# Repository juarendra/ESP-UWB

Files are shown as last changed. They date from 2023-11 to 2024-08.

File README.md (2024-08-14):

# ESP-UWB
This is PCB or Modul that combine ESP32 WROOM and DWM1004C in one Board, all pin are connected to header like ESP32 DEV KIT, and DWM1004C some pin are connected to SMD PAD on Bottom of PCB. You can find the gerber file, BOM LIST file and schematic file on this repository. 

## Table of Content

* [Product Specsification](#product-specsification)
* [Technical Spesification](#technical-spesification)
* [Priview Hardware](#priview-hardware)
* [Documentation](#documentation)
  * [Pinout Diagram](#pinout-diagram)
  * [Dimension](#dimension)
  * [BOM](#bom)
  * [Schematic](#schematic0)
  * [Example Program](#examples-program)
* [FAQ](#FAQ)

## Product Specsification
- esp32 wroom
- dwm1004c
- connected with serial uart between esp and dwm
- header i2c for oled display
- header pinout esp32
- pad smd dwm1004c
- modul charger tp4056
- switch on off

## Technical Spesification

| Features | Value |  
| --- | --- |
| Microcontroller | ESP32 |
| UWB Chip | DWM1004c |
| Dispaly | OLED 0.91 inch |
| USB To UART | FTDI 232XS |
| IC Charger | TP4056 |
| PSU | M3406 2.0V to 6.0V to 3.3V 800mA|

## Preview Hardware
<p align="center">
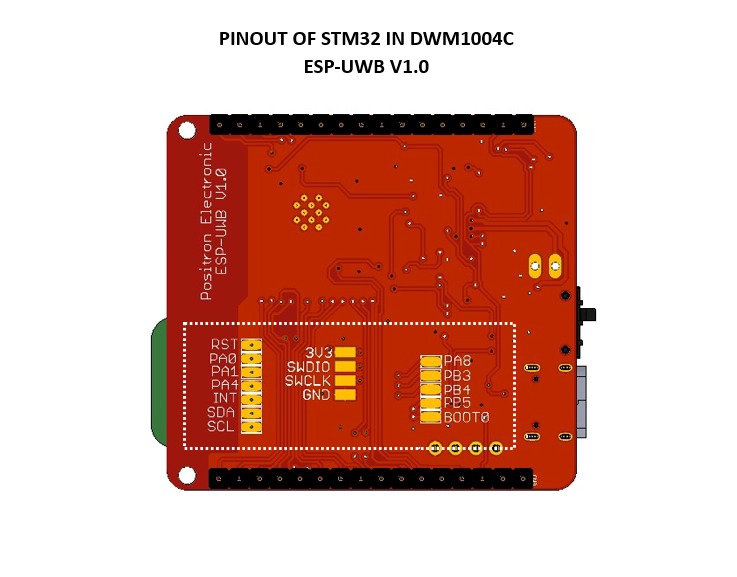
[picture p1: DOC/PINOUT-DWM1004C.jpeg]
  
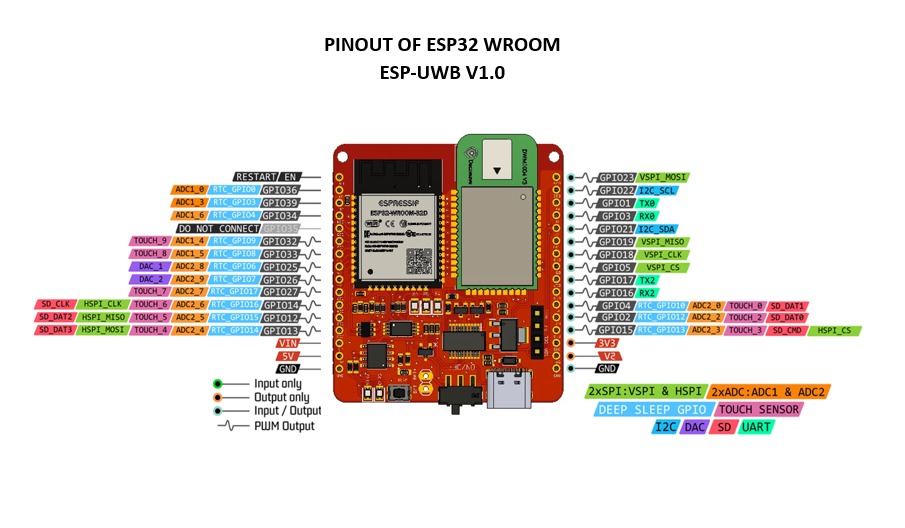
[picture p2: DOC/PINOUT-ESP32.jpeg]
  
</p>

## Documentation
### PINOUT
<p align="center">
  
</p>

### Dimension
- [Dimension](https://github.com/juarendra/ESP-UWB/blob/main/HARDWARE/dimension_esp-uwb.pdf)
### BOM
- [BOM](https://github.com/juarendra/ESP-UWB/blob/main/DOC/BOM_ESP-UWB.csv)
### Schematic
- Not Available
### Example Program
- [Example Program](https://github.com/juarendra/ESP-UWB/tree/main/FIRMWARE)

## Detail Connection ESP32 to DWM1004c
<p align="center">
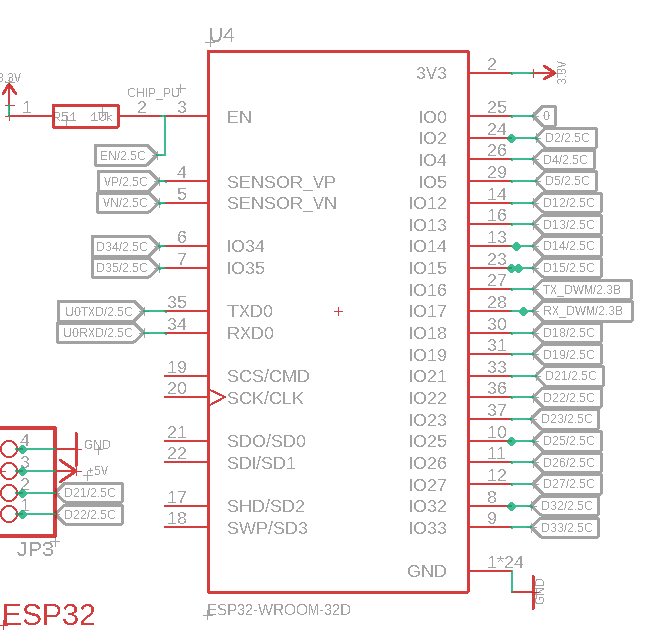
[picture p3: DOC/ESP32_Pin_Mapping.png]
  
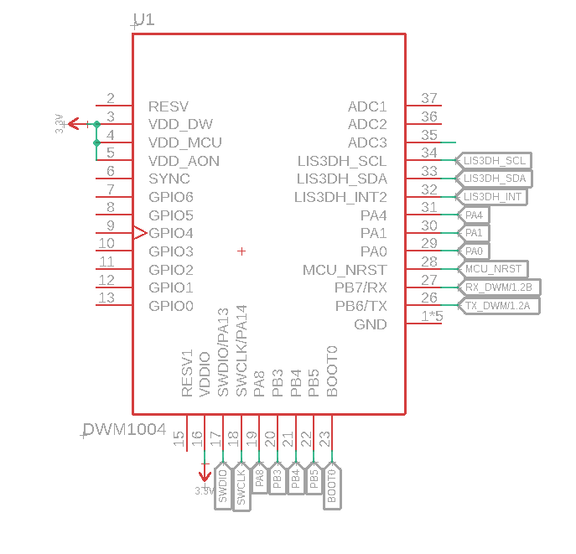
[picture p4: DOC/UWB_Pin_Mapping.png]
  
</p>
ESP32 and DWM1004c are connection with serial , you can see that ESP32 use pin IO16 and IO7 for serial and connected with DWM1004C with pin PB7 and PB6. Serial Connection is interface that STM32L have, and STM32 connected with DMW1000 with SPI. You must flash STM32 for reading data from DWM1000 and send it VIA Serial to ESP32.

You can flash STM32L using STlink and connected to SMD pad on Bottom of PCB

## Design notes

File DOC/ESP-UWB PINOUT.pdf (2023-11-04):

PINOUT OF STM32 IN DWM1004C ESP-UWB V1.0

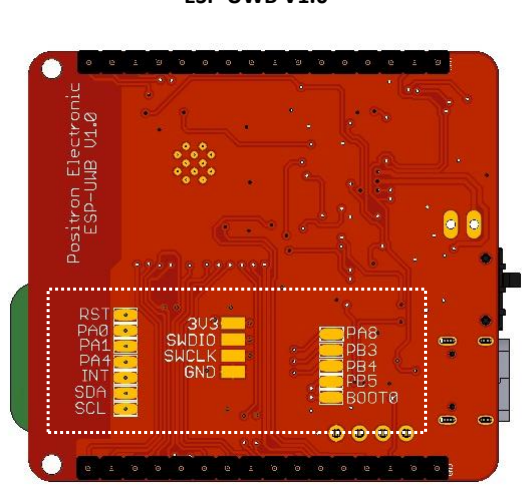
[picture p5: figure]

PINOUT OF ESP32 WROOM
ESP-UWB V1.0

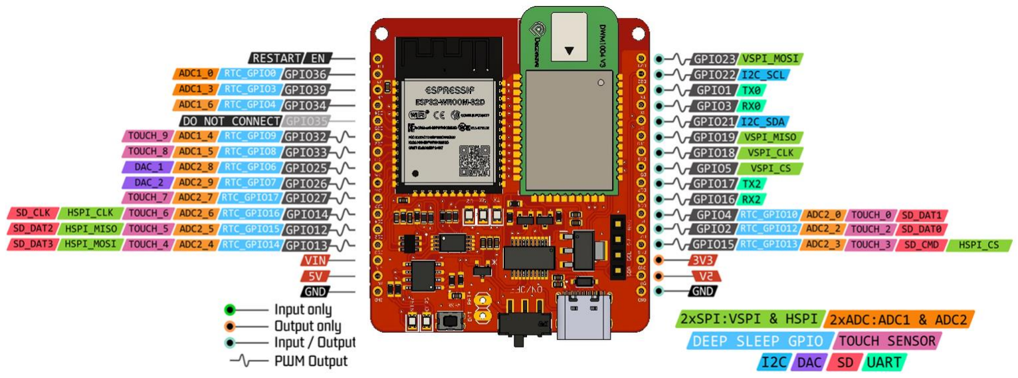
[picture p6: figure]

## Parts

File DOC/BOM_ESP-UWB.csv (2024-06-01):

Qty | Value | Device | Package | Parts | Description | AVAILABILITY | CHECK_PRICES | DESCRIPTION | DIGIKEY_PARTNUMBER | DIGIKEY_PRICE-STOCK | HEIGHT | LCSC_PART_NUMBER | LCSC_PRICE-STOCK | MANUFACTURER_NAME | MANUFACTURER_PART_NUMBER | MF | MOUSER_PART_NUMBER | MOUSER_PRICE-STOCK | MP | PACKAGE | POPULARITY | PRICE | PURCHASE-URL | SNAPEDA_LINK | VALUE
2 |  | HEADER-1X16_MIN | 1X16_ROUND_MIN | JP1, JP2 | PIN HEADER
1 |  | HEADER-1X4ROUND | 1X04_ROUND | JP3 | PIN HEADER
1 |  | PINHD-1X2 | 1X02 | BATT | PIN HEADER |  |  |  |  |  |  |  |  |  |  |  |  |  |  |  | 98
1 | 1.2k | ESR03EZPJ102 | RESC1608X55N | R8 | Thick Film Resistors - SMD 0603 1Kohm 5% Anti Surge AEC-Q200 |  |  | Thick Film Resistors - SMD 0603 1Kohm 5% Anti Surge AEC-Q200 | RHM1.0KDCT-ND | https://www.digikey.com/product-detail/en/rohm-semiconductor/ESR03EZPJ102/RHM1-0KDCT-ND/1762924 | 0.55mm |  |  | ROHM Semiconductor | ESR03EZPJ102 |  | 755-ESR03EZPJ102 | https://www.mouser.co.uk/ProductDetail/ROHM-Semiconductor/ESR03EZPJ102?qs=DyUWGjl%252BcVvjMuV%252BzioV7Q%3D%3D |  |  |  |  |  |  | 1k
1 | 100 | ESR03EZPJ102 | RESC1608X55N | R9 | Thick Film Resistors - SMD 0603 1Kohm 5% Anti Surge AEC-Q200 |  |  | Thick Film Resistors - SMD 0603 1Kohm 5% Anti Surge AEC-Q200 | RHM1.0KDCT-ND | https://www.digikey.com/product-detail/en/rohm-semiconductor/ESR03EZPJ102/RHM1-0KDCT-ND/1762924 | 0.55mm |  |  | ROHM Semiconductor | ESR03EZPJ102 |  | 755-ESR03EZPJ102 | https://www.mouser.co.uk/ProductDetail/ROHM-Semiconductor/ESR03EZPJ102?qs=DyUWGjl%252BcVvjMuV%252BzioV7Q%3D%3D |  |  |  |  |  |  | 1k
8 | 100nf | 885012206071 | CAPC1608X87N | C2, C5, C8, C9, C10, C14, C15, C16 | Wurth Elektronik 0603 WCAP-CSGP 100nF Ceramic Multilayer Capacitor, 25 V dc, +125C, X7R Dielectric, +/-10% |  |  | Wurth Elektronik 0603 WCAP-CSGP 100nF Ceramic Multilayer Capacitor, 25 V dc, +125C, X7R Dielectric, +/-10% | 732-7989-1-ND | https://www.digikey.com/product-detail/en/w%C3%BCrth-elektronik/885012206071/732-7989-1-ND/5454616 | 0.87mm |  |  | Wurth Elektronik | 885012206071 |  | 710-885012206071 | https://www.mouser.co.uk/ProductDetail/Wurth-Elektronik/885012206071?qs=0KOYDY2FL2%2FEBQkuHgvarg%3D%3D |  |  |  |  |  |  | 100nf
5 | 10k | ESR03EZPJ103 | RESC1608X55N | R1, R20, R50, R51, R54 | Thick Film Resistors - SMD 0603 10Kohm 5% Anti Surge AEC-Q200 |  |  | Thick Film Resistors - SMD 0603 10Kohm 5% Anti Surge AEC-Q200 | RHM10KDCT-ND | https://www.digikey.com/product-detail/en/rohm-semiconductor/ESR03EZPJ103/RHM10KDCT-ND/1762925 | 0.55mm |  |  | ROHM Semiconductor | ESR03EZPJ103 |  | 755-ESR03EZPJ103 | https://www.mouser.com/Search/Refine.aspx?Keyword=755-ESR03EZPJ103 |  |  |  |  |  |  | 10k
2 | 10nf | 885012206089 | CAPC1608X87N | C3, C12 | Wurth Elektronik 0603 WCAP-CSGP 10nF Ceramic Multilayer Capacitor, 50 V dc, +125C, X7R Dielectric, +/-10% |  |  | Wurth Elektronik 0603 WCAP-CSGP 10nF Ceramic Multilayer Capacitor, 50 V dc, +125C, X7R Dielectric, +/-10% | 732-8007-1-ND | https://www.digikey.com/product-detail/en/w%C3%BCrth-elektronik/885012206089/732-8007-1-ND/5454634 | 0.87mm |  |  | Wurth Elektronik | 885012206089 |  | 710-885012206089 | https://www.mouser.co.uk/ProductDetail/Wurth-Elektronik/885012206089?qs=0KOYDY2FL28GvSbKh319Tw%3D%3D |  |  |  |  |  |  | 10nf
1 | 1N5819HW-7 | 1N5819HW-7 | SOD3715X145N | D1 | 1N5819HW Series 40 V 1 A Surface Mount Schottky Barrier Rectifier - SOD-123 Check availability | In Stock | https://www.snapeda.com/parts/1N5819HW-7/Diodes+Inc./view-part/?ref=eda | Diode Schottky 40 V 1A Surface Mount SOD-123 |  |  |  |  |  |  |  | Diodes Inc. |  |  | 1N5819HW-7 | SOD-123 Fairchild Semiconductor |  | None | https://www.snapeda.com/api/url_track_click_mouser/?unipart_id=51510&manufacturer=Diodes Inc.&part_name=1N5819HW-7&search_term=1n5819 | https://www.snapeda.com/parts/1N5819HW-7/Diodes+Inc./view-part/?ref=snap
3 | 1k | ESR03EZPJ102 | RESC1608X55N | R5, R6, R14 | Thick Film Resistors - SMD 0603 1Kohm 5% Anti Surge AEC-Q200 |  |  | Thick Film Resistors - SMD 0603 1Kohm 5% Anti Surge AEC-Q200 | RHM1.0KDCT-ND | https://www.digikey.com/product-detail/en/rohm-semiconductor/ESR03EZPJ102/RHM1-0KDCT-ND/1762924 | 0.55mm |  |  | ROHM Semiconductor | ESR03EZPJ102 |  | 755-ESR03EZPJ102 | https://www.mouser.co.uk/ProductDetail/ROHM-Semiconductor/ESR03EZPJ102?qs=DyUWGjl%252BcVvjMuV%252BzioV7Q%3D%3D |  |  |  |  |  |  | 1k
1 | 1uF | CAP_CERAMIC0603_NO | 0603-NO | C4 | Ceramic Capacitors
2 | 1uf | 885012206071 | CAPC1608X87N | C11, C13 | Wurth Elektronik 0603 WCAP-CSGP 100nF Ceramic Multilayer Capacitor, 25 V dc, +125C, X7R Dielectric, +/-10% |  |  | Wurth Elektronik 0603 WCAP-CSGP 100nF Ceramic Multilayer Capacitor, 25 V dc, +125C, X7R Dielectric, +/-10% | 732-7989-1-ND | https://www.digikey.com/product-detail/en/w%C3%BCrth-elektronik/885012206071/732-7989-1-ND/5454616 | 0.87mm |  |  | Wurth Elektronik | 885012206071 |  | 710-885012206071 | https://www.mouser.co.uk/ProductDetail/Wurth-Elektronik/885012206071?qs=0KOYDY2FL2%2FEBQkuHgvarg%3D%3D |  |  |  |  |  |  | 100nf
3 | 330 | ERJ-H3EF3300V | ERJH3 | R2, R4, R11 | Power Rating 0.125W,Resistance 330 Ohm,LxW(EIA) 1.6 x 0.8 (EIA:0603) mm |  |  | Power Rating 0.125W,Resistance 330 Ohm,LxW(EIA) 1.6 x 0.8 (EIA:0603) mm |  |  | mm |  |  | Panasonic | ERJ-H3EF3300V |  | 667-ERJ-H3EF3300V | https://www.mouser.co.uk/ProductDetail/Panasonic/ERJ-H3EF3300V?qs=eP2BKZSCXI61roRLPi8W7w%3D%3D |  |  |  |  |  |  | 330
1 | 40k2 | ERJ-S03F4022V | RESC1608X55N | R37 | Thick Film Resistors - SMD 0603 40.2Kohms 1% Anti-Sulfur |  |  | Thick Film Resistors - SMD 0603 40.2Kohms 1% Anti-Sulfur |  |  | 0.55mm |  |  | Panasonic | ERJ-S03F4022V |  | 667-ERJ-S03F4022V | https://www.mouser.com/Search/Refine.aspx?Keyword=667-ERJ-S03F4022V
2 | 47k | ERJ-H3EF3300V | ERJH3 | R15, R16 | Power Rating 0.125W,Resistance 330 Ohm,LxW(EIA) 1.6 x 0.8 (EIA:0603) mm |  |  | Power Rating 0.125W,Resistance 330 Ohm,LxW(EIA) 1.6 x 0.8 (EIA:0603) mm |  |  | mm |  |  | Panasonic | ERJ-H3EF3300V |  | 667-ERJ-H3EF3300V | https://www.mouser.co.uk/ProductDetail/Panasonic/ERJ-H3EF3300V?qs=eP2BKZSCXI61roRLPi8W7w%3D%3D |  |  |  |  |  |  | 330
1 | DW01A | DW01A | SOT23-6 | IC1 | Check availability | Not in stock | https://www.snapeda.com/parts/DW01A/Fortune+Semiconductor/view-part/?ref=eda | One Cell Lithium-ion/Polymer Battery Protection IC |  |  |  |  |  |  |  | Fortune Semiconductor |  |  | DW01A | SOT-23-6 Fortune Semiconductor |  | None |  | https://www.snapeda.com/parts/DW01A/Fortune+Semiconductor/view-part/?ref=snap
1 | DWM1004 | DWM1004 | DWM1004 | U1 | Bluetooth, WiFi 802.11b/g/n, Bluetooth v4.2 + EDR, Class 1, 2 and 3 Transceiver Module 2.4GHz ~ 2.5GHz Integrated, Trace Surface Mount Check availability
1 | ESP32-WROOM-32D | ESP32-WROOM-32D | MODULE_ESP32-WROOM-32D | U4 | Bluetooth, WiFi 802.11b/g/n, Bluetooth v4.2 + EDR, Class 1, 2 and 3 Transceiver Module 2.4GHz ~ 2.5GHz Integrated, Trace Surface Mount Check availability | In Stock |  | Bluetooth, WiFi 802.11b/g/n, Bluetooth v4.2 +EDR, Class 1, 2 and 3 Transceiver Module 2.4GHz ~ 2.5GHz Integrated |  |  |  |  |  |  |  | Espressif Systems |  |  | ESP32-WROOM-32D | Module Espressif Systems |  | None | https://pricing.snapeda.com/search/part/ESP32-WROOM-32D/?ref=eda
1 | FS8205A | FS8205A | SOP65P640X120-8N | Q4 | N/A Check availability | Not in stock | https://www.snapeda.com/parts/FS8205A/Fortune+Semiconductor/view-part/?ref=eda |  |  |  |  |  |  |  |  | Fortune Semiconductor |  |  | FS8205A | Package |  | None |  | https://www.snapeda.com/parts/FS8205A/Fortune+Semiconductor/view-part/?ref=snap
1 | FT231XS-R | FT231XS-R | SOP64P599X175-20N | IC2 | FTDI Chip FT231XS-R, Interface RS232, RS422, RS485, SIE, UART 3MBd, 5 V, 20-pin, SSOP |  |  | FTDI Chip FT231XS-R, Interface RS232, RS422, RS485, SIE, UART 3MBd, 5 V, 20-pin, SSOP |  |  | 1.753mm |  |  | FTDI Chip | FT231XS-R |  | 895-FT231XS-R | https://www.mouser.co.uk/ProductDetail/FTDI/FT231XS-R?qs=Gp1Yz1mis3WduRPsgrTbtg%3D%3D
5 | Green | 150080BS75000 | LEDC2012X80N | LED1, LED2, LED3, LED4, LED5 | LED,Wurth Elektronik,150080BS75000 Wurth Elektronik 150080BS75000, WL-SMCW Series Blue LED, 470 nm 2012 (0805) Clear, Rectangle Lens SMD package |  |  | LED,Wurth Elektronik,150080BS75000 Wurth Elektronik 150080BS75000, WL-SMCW Series Blue LED, 470 nm 2012 (0805) Clear, Rectangle Lens SMD package |  |  | 0.8mm |  |  | Wurth Elektronik | 150080BS75000 |  | 710-150080BS75000 | https://www.mouser.co.uk/ProductDetail/Wurth-Elektronik/150080BS75000?qs=2kOmHSv6VfT2tBo3UPVqAQ%3D%3D |  |  |  |  |  |  | Green
1 | JS102011SAQN | JS102011SAQN | SW_JS102011SAQN | BATT_SW | <b> | In Stock | https://www.snapeda.com/parts/JS102011SAQN/C%2526K/view-part/?ref=eda | Slide Switch SPDT Surface Mount, Right Angle |  |  |  |  |  |  |  | C&K |  |  | JS102011SAQN | None |  | None | https://pricing.snapeda.com/search?q=JS102011SAQN&ref=eda | https://www.snapeda.com/parts/JS102011SAQN/C%2526K/view-part/?ref=snap
1 | KMR2 | SWITCH_TACT_SMT4.6X2.8 | BTN_KMR2_4.6X2.8 | SW2 | SMT Tact Switches
1 | M3406-ADJ | M3406-ADJ | SOT95P280X100-5N | IC4 | Step-down type SOT-23-5 DC-DC Converters ROHS |  |  | Step-down type SOT-23-5 DC-DC Converters ROHS |  |  | 1mm | C83224 | https://www.lcsc.com/product-detail/DC-DC-Converters_XI-AN-Aerosemi-Tech-M3406-ADJ_C83224.html | XI'AN Aerosemi Tech | M3406-ADJ
1 | MLF2012A2R2KT000 | MLF2012A2R2KT000 | INDC2012X105N | L1 | 2.2 H Shielded Multilayer Inductor 50 mA 500mOhm Max 0805 (2012 Metric) |  |  | 2.2 H Shielded Multilayer Inductor 50 mA 500mOhm Max 0805 (2012 Metric) |  |  | 1.05mm |  |  | TDK | MLF2012A2R2KT000 |  | 810-MLF2012A2R2KT000 | https://www.mouser.co.uk/ProductDetail/TDK/MLF2012A2R2KT000?qs=pLY5GE0xrmL3Y2Jw%2FEGjFg%3D%3D
2 | MMBT3904-TP | MMBT3904-TP | SI2305TP | Q5, Q6 | Bipolar Transistors - BJT 40V |  |  | Bipolar Transistors - BJT 40V |  |  | mm |  |  | Micro Commercial Components (MCC) | MMBT3904-TP |  | 833-MMBT3904-TP | https://www.mouser.co.uk/ProductDetail/Micro-Commercial-Components-MCC/MMBT3904-TP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
1 | SI2301BDS-T1-E3 | SI2301BDS-T1-E3 | SOT95P237X112-3N | U6 | MOSFET Check availability | In Stock | https://www.snapeda.com/parts/SI2301BDS-T1-E3/Vishay+Siliconix/view-part/?ref=eda | MOSFET,P-Ch,VDSS -20V,RDS(ON) 0.08Ohm,ID -2.2A,TO-236 (SOT-23),PD 0.7W,VGS +/-8V | Siliconix / Vishay SI2301BDS-T1-E3 |  |  |  |  |  |  |  | Vishay |  |  | SI2301BDS-T1-E3 | SOT-23-3 Vishay Siliconix |  | None | https://www.snapeda.com/api/url_track_click_mouser/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 | https://www.snapeda.com/parts/SI2301BDS-T1-E3/Vishay+Siliconix/view-part/?ref=snap
1 | TP4056 | TP4056 | SOP127P600X175-9N | U3 | Complete single cell Li-Ion battery with a constant current / constant voltage linear charger Check availability | Not in stock | https://www.snapeda.com/parts/TP4056/NanJing+Top+Power+ASIC+Corp./view-part/?ref=eda | Complete single cell Li-Ion battery with a constant current / constant voltage linear charger |  |  |  |  |  |  |  | NanJing Top Power ASIC Corp. |  |  | TP4056 | Package |  | None |  | https://www.snapeda.com/parts/TP4056/NanJing+Top+Power+ASIC+Corp./view-part/?ref=snap
1 | TYPE-C-31-M-12 | TYPE-C-31-M-12 | HRO_TYPE-C-31-M-12 | J1 | Check availability | Not in stock | https://www.snapeda.com/parts/TYPE-C-31-M-12/HRO+Electronics+Co.%252C+Ltd./view-part/?ref=eda | USB Connectors 24 Receptacle 1 8.94*7.3mm RoHS |  |  |  |  |  |  |  | HRO Electronics Co., Ltd. |  |  | TYPE-C-31-M-12 | Package |  | None |  | https://www.snapeda.com/parts/TYPE-C-31-M-12/HRO+Electronics+Co.%252C+Ltd./view-part/?ref=snap
4 | WIREPADSMD1,27-254 | WIREPADSMD1,27-254 | SMD1,27-2,54 | 3V3, GND, SWCLK, SWDIO | Wire PAD connect wire on PCB |  |  |  |  |  |  |  |  |  |  |  |  |  |  |  | 11
12 | WIREPADSMD5-2,5 | WIREPADSMD5-2,5 | 5-2,5 | BOOT0, INT, PA0, PA1, PA4, PA8, PB3, PB4, PB5, RST, SCL, SDA | Wire PAD connect wire on PCB |  |  |  |  |  |  |  |  |  |  |  |  |  |  |  | 3

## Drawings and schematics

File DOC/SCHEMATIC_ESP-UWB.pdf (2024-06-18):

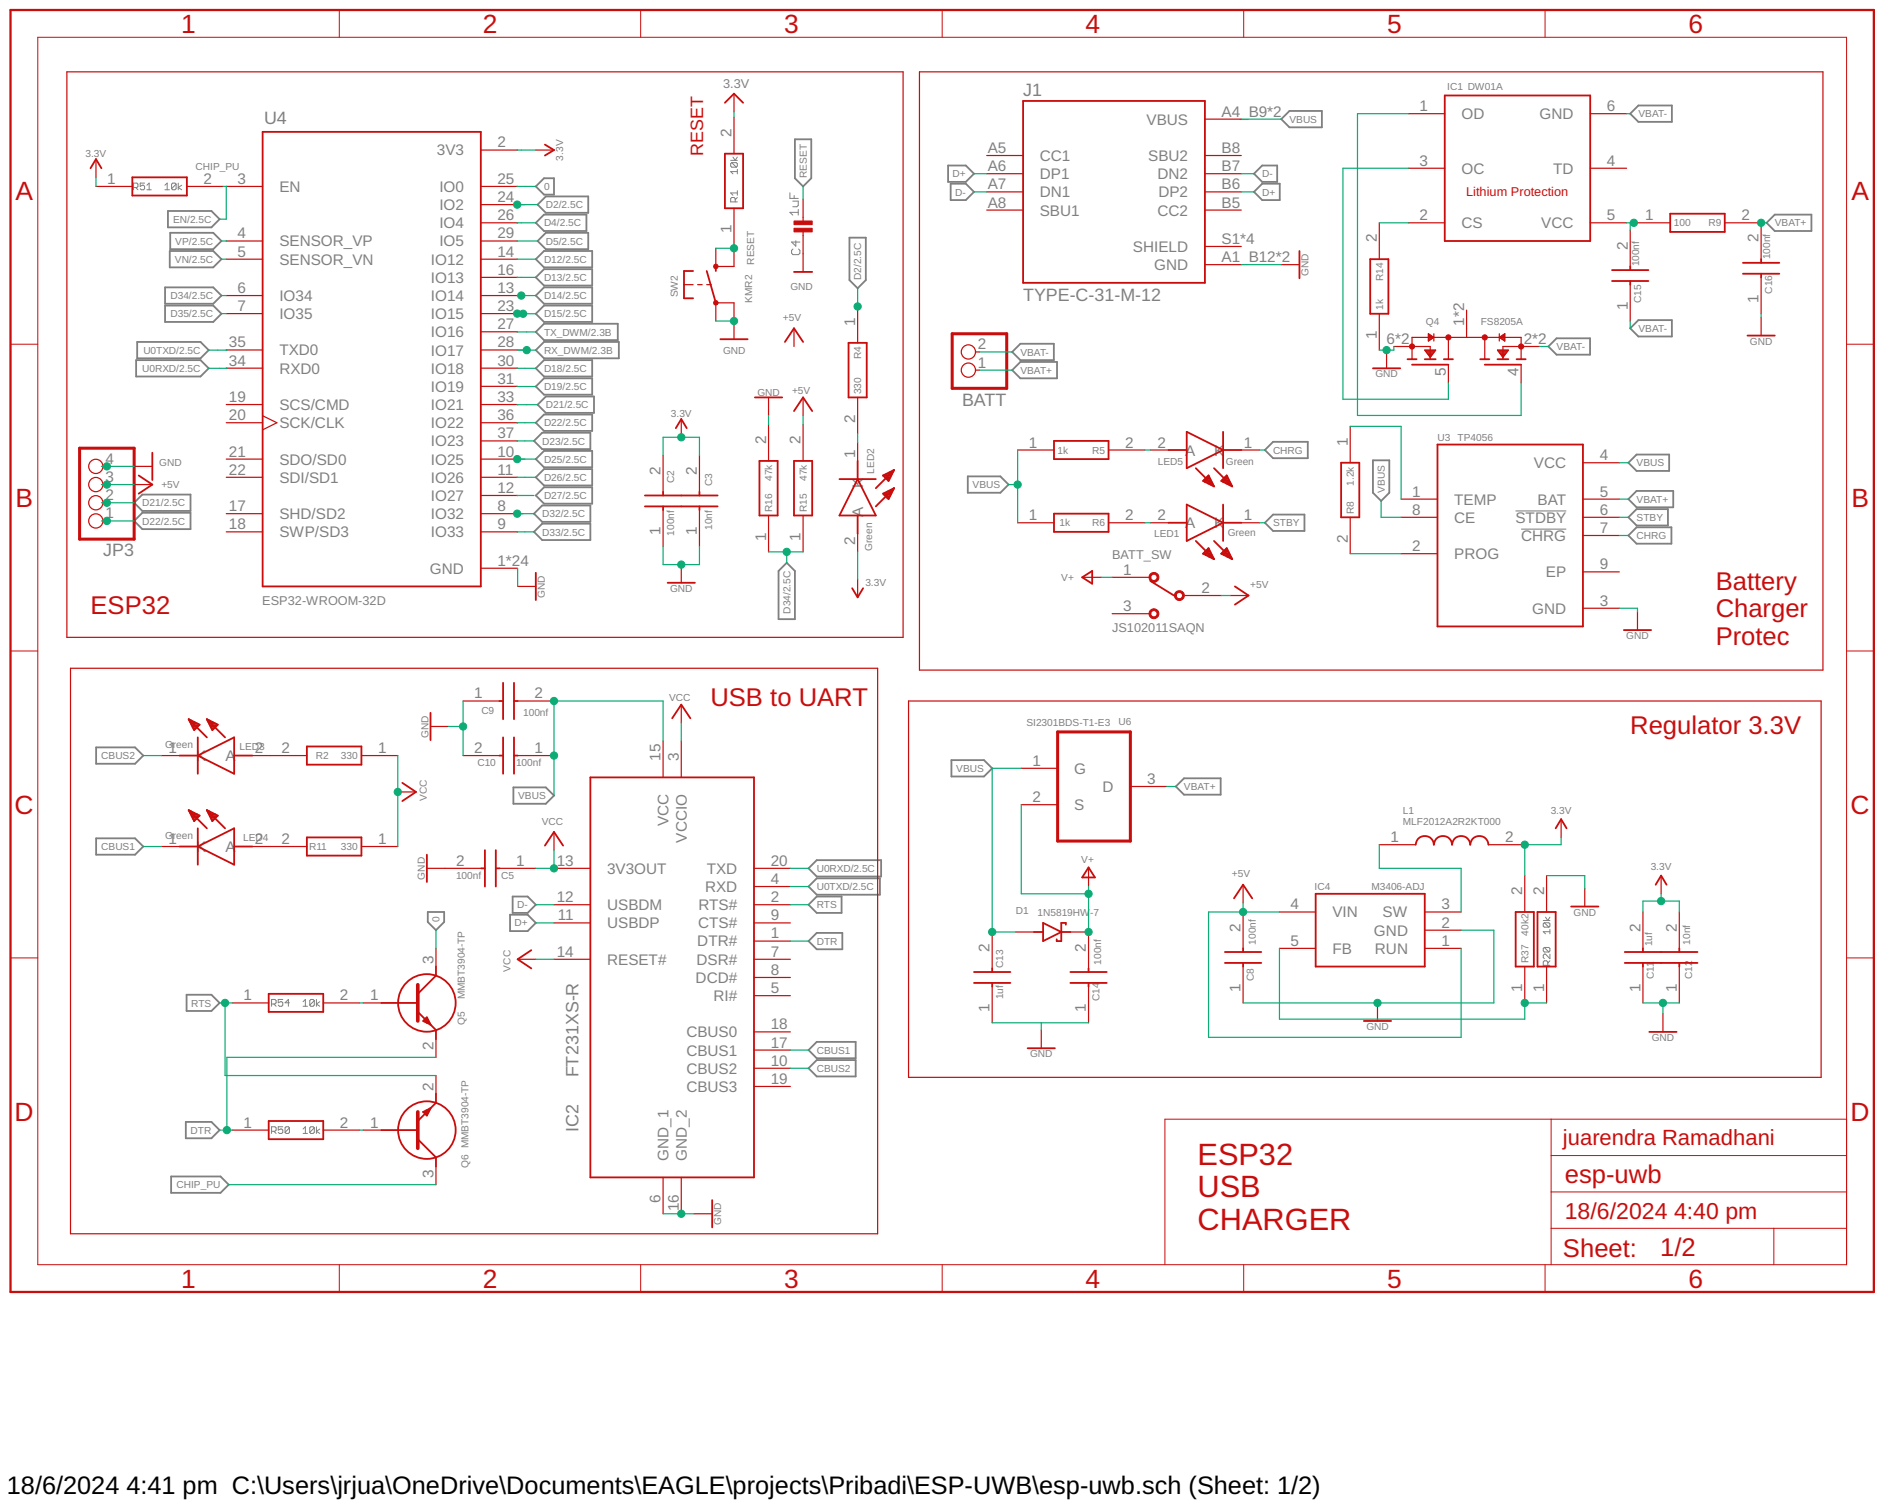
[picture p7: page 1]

18/6/2024 4:41 pm C:\Users\jrjua\OneDrive\Documents\EAGLE\projects\Pribadi\ESP-UWB\esp-uwb.sch (Sheet: 1/2)

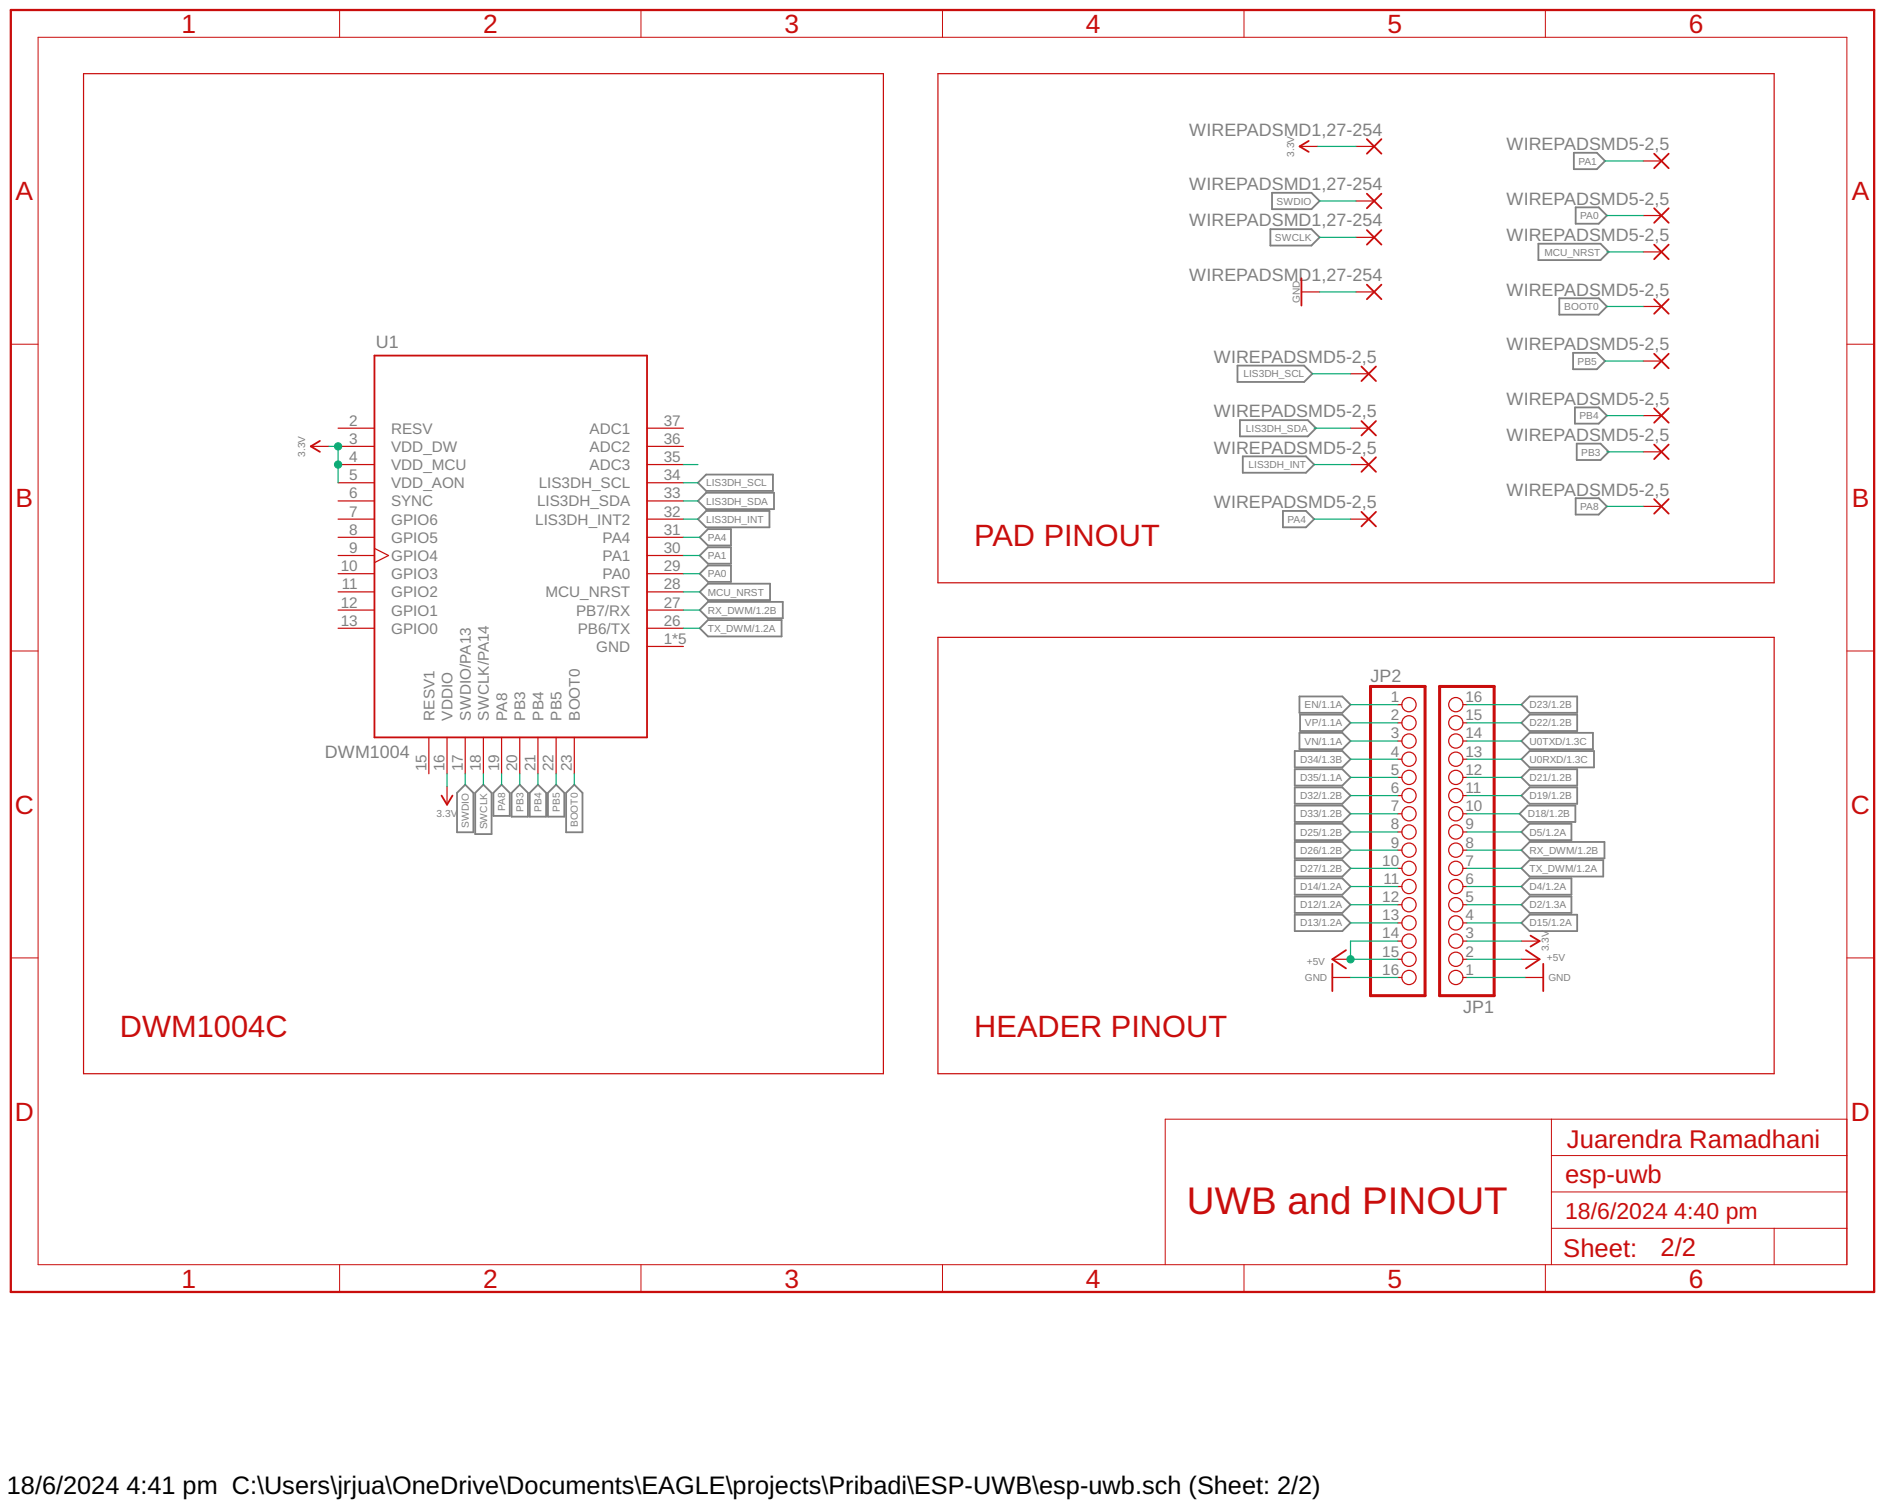
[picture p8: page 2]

18/6/2024 4:41 pm C:\Users\jrjua\OneDrive\Documents\EAGLE\projects\Pribadi\ESP-UWB\esp-uwb.sch (Sheet: 2/2)

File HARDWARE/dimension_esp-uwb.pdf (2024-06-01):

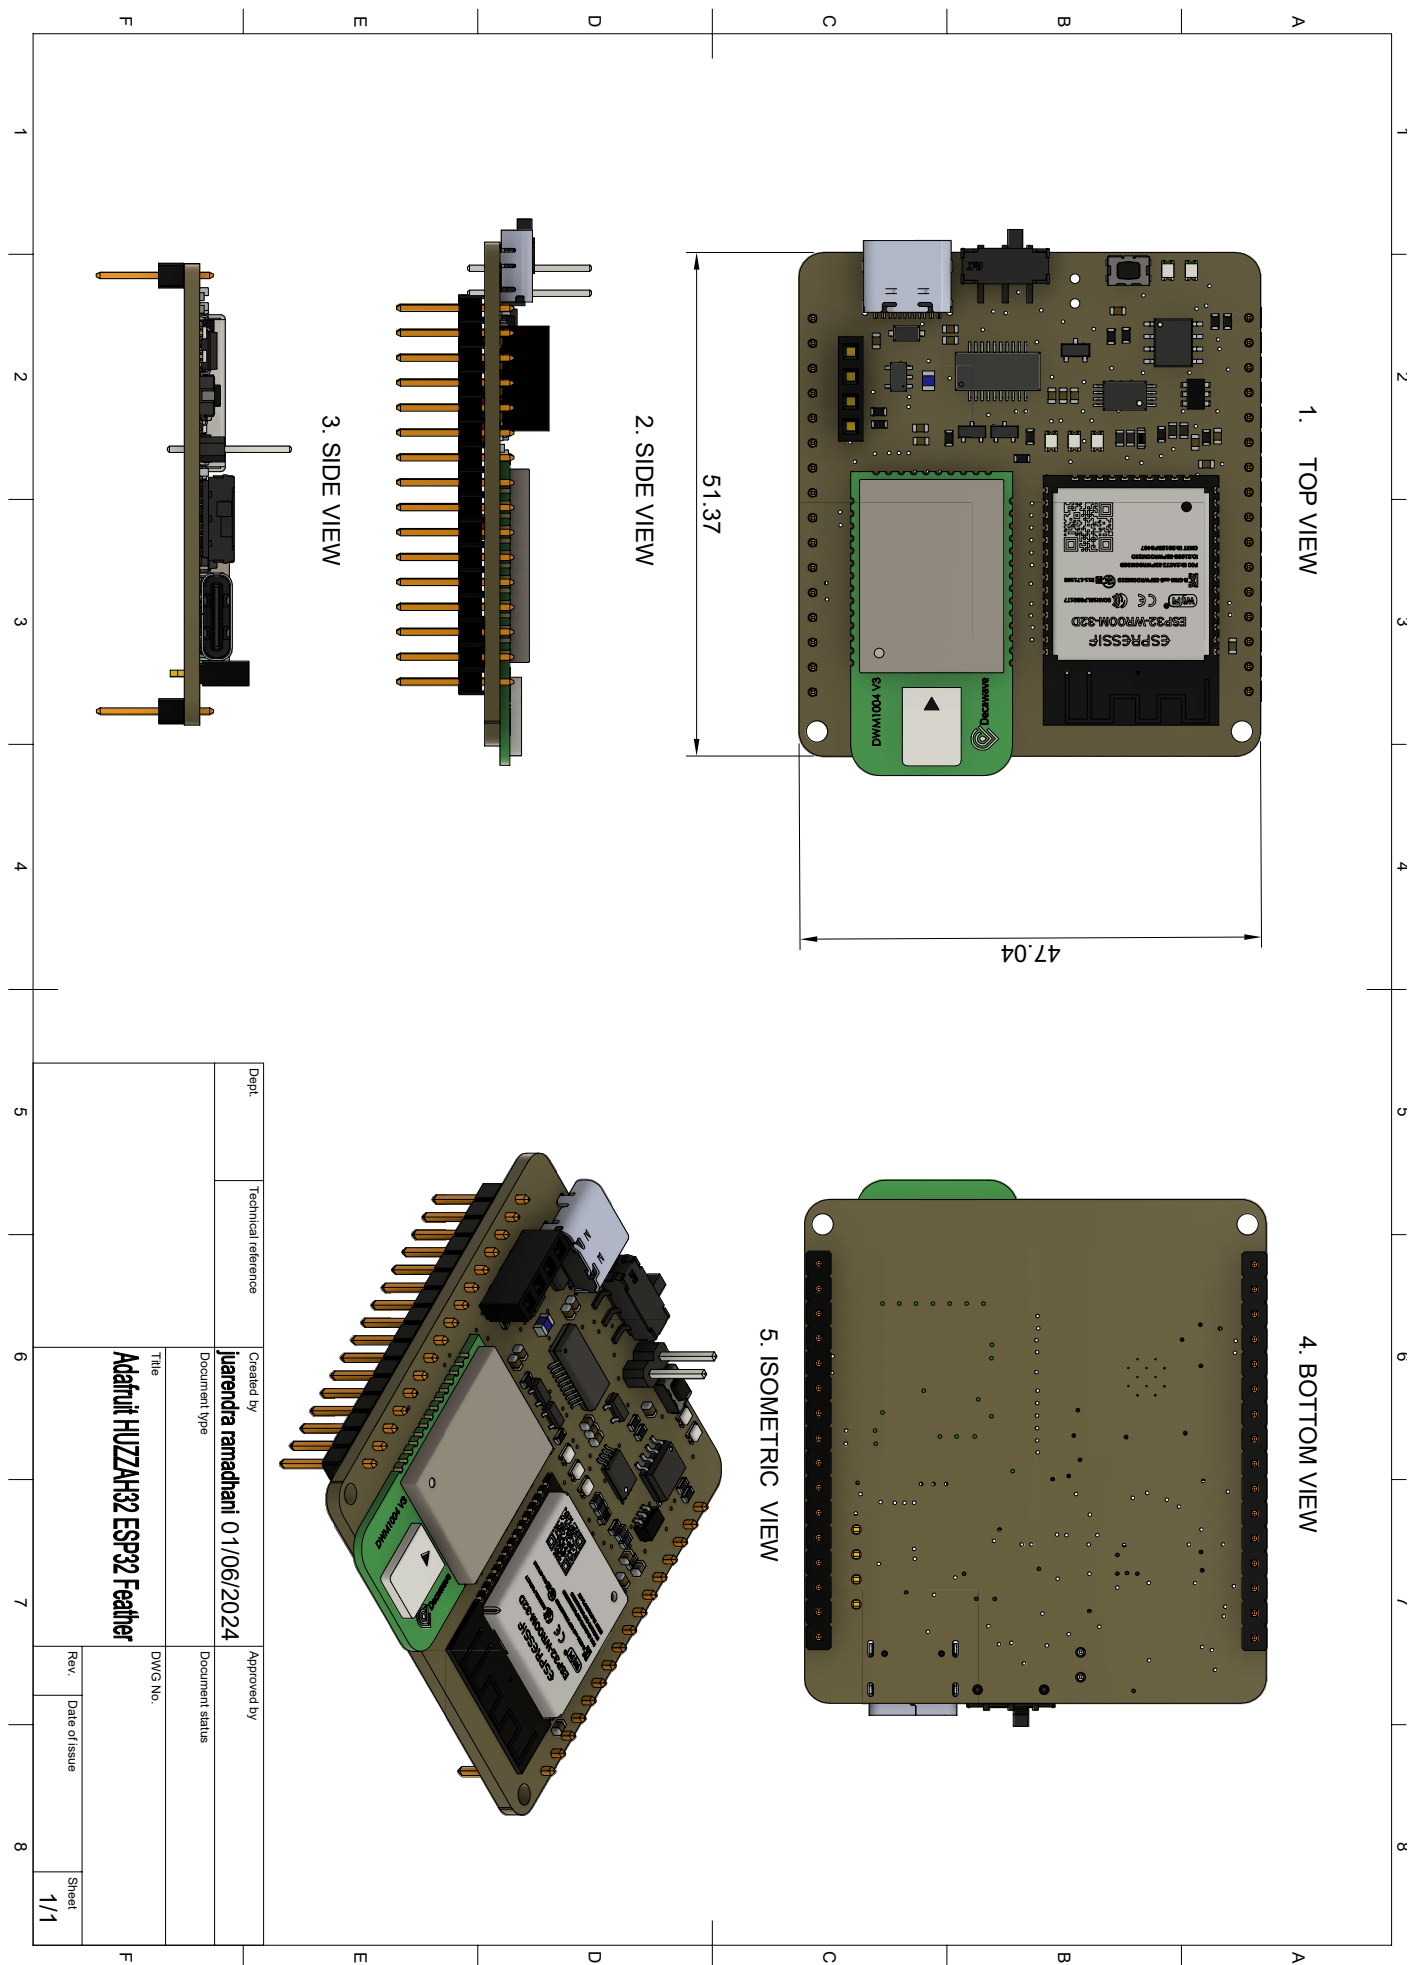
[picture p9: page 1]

1 A 2 3 4 5 6 7 8 1 2 3 4 5 6 7 8 FEDCB FEDCBA Dept. Technical reference Created by Approved by Title DWG No. Document type Document status Rev. Date of issue Sheet 01/06/2024 1/1

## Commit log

2024-06-01 update ic stepdown 3V3
    [copper_bottom.gbr, copper_top.gbr, drill_1_16.xln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]
2024-06-01 DOC: add BOM LIST
    [BOM_ESP-UWB.csv]
2024-06-01 DOC: edit readme for link dimension and bom
2024-06-02 DOC: add documentation conection esp32 and DWM1004C
2024-06-02 DOC: add firmware for STM32L
2024-06-18 FIX: fix led pin io2 ond katoda connected to 3v3 otherwise gns
    [copper_top.gbr, drill_1_16.xln, gerber_job.gbrjob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]
